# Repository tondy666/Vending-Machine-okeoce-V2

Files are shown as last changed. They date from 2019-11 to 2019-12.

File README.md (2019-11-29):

# simple-vending-mechine
merupakan project untuk sistem embeded yaitu bertujuan untuk membuat vending mechine dengan konsep sederhana dengan mengguunakan microkontroller STM32F103C8

SIMPLE VENDING MECHINE
Penerapan algoritma vending mechine secara sederhana dengan mengunakan Algoritma State Mechine dengan mengunakan Schedular(Timer) pada STM32F103C8.
dengan menggunakan Presacaller adalah 0 dan Auto Reload Register adalah 72 diharapkan melakukan task yang ditentukan setiap 1uS

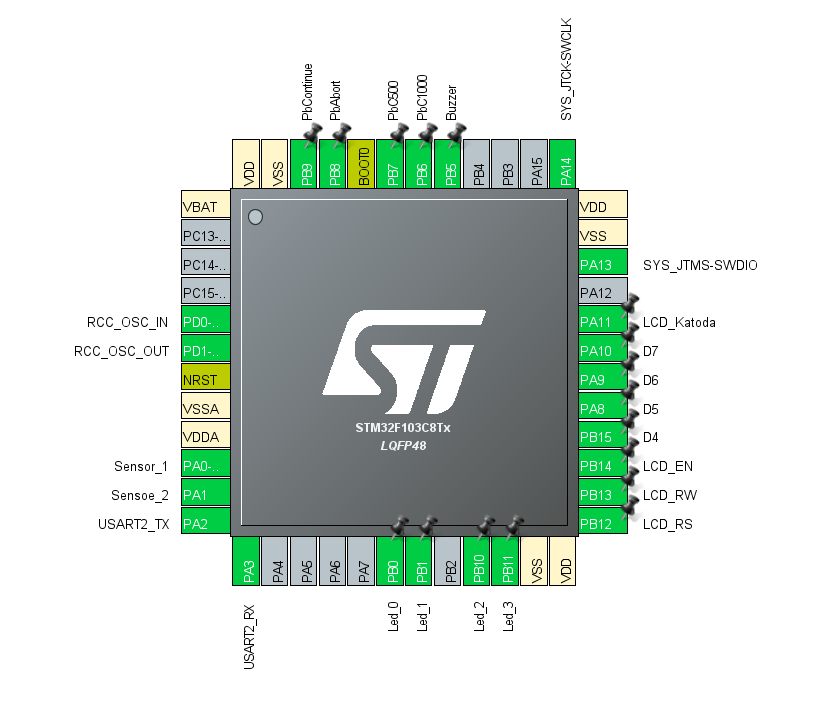
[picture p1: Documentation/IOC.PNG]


Diatas merupakan pinout konfigurasi yang digunakan pada project kali ini. menggunakan LCD 20x4 dan LED 5mm untuk interface

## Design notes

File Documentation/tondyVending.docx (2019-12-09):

LAPORAN PROJECT SISTEM EMBEDDED

APLIKASI TIMESTATE MACHINE PADA VENDING MACHINE

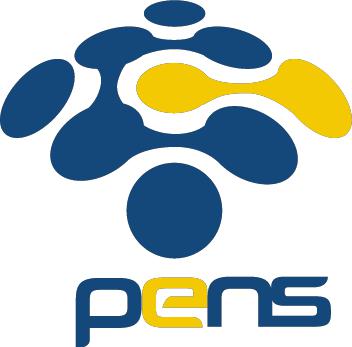
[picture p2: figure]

Disusun Oleh :

Tondi Taufiq Akbar Nasution 1110171048

3 D4 ELEKTRONIKA B

PROGRAM STUDI TEKNIK ELEKTRONIKA

DEPARTEMEN ELEKTRO

POLITEKNIK ELEKTRONIKA NEGERI SURABAYA

2019

LAPORAN PROJECT SISTEM EMBEDDED

APLIKASI TIMESTATE MACHINE PADA VENDING MACHINE

I. TUJUAN
1. Mahasiswa dapat membuat program timestate machine dengan menggunakan ARM
2. Mahasiswa dapat mengimplementasikan program timestate machine menggunakan pemrograman berstruktur dan mekanisme time out dalam suatu alat.
II. DASAR TEORI

II.1 ARM (STM32F103C8T6)

Arsitektur ARM merupakan arsitektur prosesor (https://id.wikipedia.org/wiki/Prosesor) 32-bit RISC yang dikembangkan oleh ARM Limited. Dikenal sebagai Advanced RISC Machine di mana sebelumnya dikenal sebagai Acorn RISC Machine. Pada awalnya merupakan prosesor desktop yang sekarang didominasi oleh keluarga x86. Namun desain yang sederhana membuat prosesor ARM cocok untuk aplikasi berdaya rendah. Hal ini membuat prosesor ARM mendominasi pasar mobile electronic dan embedded system di mana membutuhkan daya dan harga yang rendah.

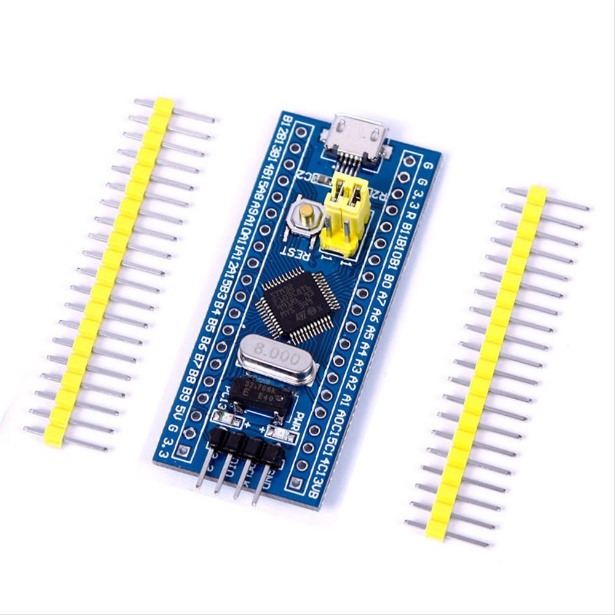
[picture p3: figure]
Hasil gambar untuk pengertian arm stm32f103c8t6"

STM32 adalah mikrokontroler berbasis inti prosesor 32 bit RISC ARM Cortex-M7, Cortex-M4F, Cortex-M3, Cortex-M0+, dan Cortex-M0 dari STMicrelectronics. Mikrokontroler ini mempunyai frekuensi clock tinggi, umumnya berada pada kisaran 72MHz atau lebih.

Gambar II.1 STM32F103C8T6

II.2 I2C LCD 20X4

LCD atau Liquid Crystal Display adalah suatu jenis media display (tampilaan) yang dibuat menggunakan teknologi CMOS logic yang bekerja dengan tidak menghasilkan cahaya namun memantulkan cahaya yang ada disekeliingnya terhadap front-lit atau mentransmisikan cahaya dari back-lit. LCD berfungsi sebagai penampil data baik dalam bentuk huruf, angka, karakter ataupun grafik.

Yang dimaksud dengan I2C LCD adalah modul LCD yang dikendalikan secara serial sinkron dengan protocol I2C/IIC (Inter Integrated Circuit) atau TWI (Two Wire Interface). Normalnya, modul LCD dikendalikan secara parallel baik untuk jalur data maupun kontrolnya. Namun, jalur parallel akan memakan banyak pin disisi controller (misal Arduino, Android, Komputer, dll). Setidaknya kita akan membutuhkan 6 atau 7 pin untuk mengendalikan sebuah modul LCD. Dengan demikian untuk sebuah controller yang “sibuk” dan harus, mengendalikan banyak I/O, menggunakan jalur parallel adalah solusi yang kurang tepat.

Arduino sudah mendukung protocol I2C/IIC. Di papan Arduino Uno, port I2C terletak pada pin A4 untuk jalur SDA (Serial Data) dan pin A5 untuk jalur SCL (Serial Clock), jangan lupa untuk menghubungkan jalur kabel ground antara Arduino dengan perangkat I2C client. Untuk sisi software, Arduino sudah cukup membantu kita bekerja dengan protocol ini melalui library ‘Wire.h’. Berikutnya, library ini akan dimanfaatkan untuk mengkonversi jalur parallel LCD menjadi jalur serial I2C. Kita dapat secara mudah melakukannya, namun agar lebih mudah kita dapat melakukannya dengan menggunakan library LiquidCrystal_I2C.h (bersama dengan library LCD.h).

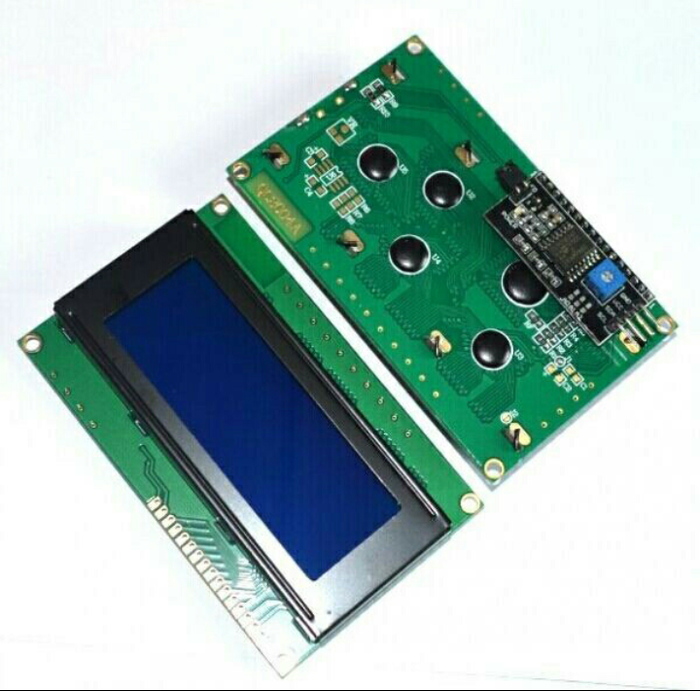
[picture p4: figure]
Hasil gambar untuk lcd 20x4 i2c"

Gambar II.2 Konfigurasi pin I2C LCD 20x4

III. ALAT DAN BAHAN
1. Laptop yang sudah terinstall software Arduino IDE 1 buah
2. ARM (STM32F103C8T6) 1 buah
3. I2C LCD 20x4 1 buah
4. ST-Link 1 buah
5. USB TTL 1 buah
6. Push Button 4 buah
7. Kabel jumper secukupnya
8. Kertas Duplex 1 buah
9. Lem tembak 1 buah
10. Cutter 1 buah
11. Gunting 1 buah
IV. PROSEDUR

IV.I Pemrograman dan Penyetinggan Pada STM32CubeIDE

1. Membuka aplikasi STM32CubeIDE pada PC
2. Memastikan USB TTL sudah terdeteksi oleh PC
3. Menuliskan program seperti dibawah ini :
  3.1 Program Pada task.c

#include "main.h"

#include "MyTask.h"

#include "MyLCD.h"

#include "MyUART.h"

#include "MySeOS.h"

unsigned char Button_Continue(void);

unsigned char Button_Abort(void);

unsigned char Button_C1000(void);

unsigned char Button_C500(void);

void Led_Init(void);

void Led_IndexStart(void);

void Led_c500(void);

void Led_Buffer(void);

void Led_Abort(void);

void Led_Continue(void);

#define Continue HAL_GPIO_ReadPin(PbContinue_GPIO_Port, PbContinue_Pin)==GPIO_PIN_RESET

#define Abort HAL_GPIO_ReadPin(PbAbort_GPIO_Port, PbAbort_Pin)==GPIO_PIN_RESET

#define Pb1000 HAL_GPIO_ReadPin(PbC1000_GPIO_Port, PbC1000_Pin)==GPIO_PIN_RESET

#define pb500 HAL_GPIO_ReadPin(PbC500_GPIO_Port, PbC500_Pin)==GPIO_PIN_RESET

#define BuzzerOn HAL_GPIO_WritePin(Buzzer_GPIO_Port, Buzzer_Pin, GPIO_PIN_SET)

#define BuzzerOff HAL_GPIO_WritePin(Buzzer_GPIO_Port, Buzzer_Pin, GPIO_PIN_RESET)

enum state {start, startdelay, finishdelay, koinkurang, kembali, buffer, index_start, c500, dropStuff, dropCoin, batal} Condition;

volatile uint32_t timeout=0;

volatile uint32_t i=0;

volatile uint8_t state_kembali=0;

unsigned int Coint_500=0;

unsigned int Coint_1000=0;

volatile uint64_t Jml_tunai = 0;

volatile uint16_t Coin=0;

volatile uint16_t Coin_temp=0;

volatile uint64_t Jml_kembali=0;

char dis_coint;

_Bool Kembali500 =0;

_Bool Kembali1000 =0;

_Bool Abort500=0;

_Bool Abort1000=0;

_Bool AbortTotal=0;

_Bool RunEnable =1;

void MyTask_Init(void)

{

timeout=0;

Condition=start;

Led_Init();

LCD_Init();

}

void MyTask_Run(void)

{

switch(Condition){

case start:

{

LCD_SetCursor(0, 0);LCD_Print("Vending Machine");

LCD_SetCursor(0, 1);LCD_Print("OKE OCE 2019");

Led_Init();

Condition=startdelay;

break;

}

case startdelay:

{

BuzzerOn;

if(++timeout>250000){

LCD_SetCursor(0, 2);LCD_Print("Masukkan Coin :");

timeout=0;

BuzzerOff;

MyTask_Display(RunEnable);

Condition=index_start;

}

break;

}

case c500:

{

Led_c500();

if(Button_C500()){

Coin=5;

Coin_temp+=5;

Jml_tunai+=5;

MyTask_Display(RunEnable);

Condition=buffer;

}

if(Button_C1000()){

Coin=10;

Coin_temp+=10;

Kembali500=!(Kembali500);

Condition=kembali;

}

if(Button_Abort()){

Led_Abort();

LCD_Clear();

LCD_SetCursor(0, 0);LCD_Print("Transaksi gagal");

Condition=batal;

}

if(Button_Continue()){

BuzzerOn;

LCD_Clear();

LCD_SetCursor(0, 1);LCD_Print("Transaksi Gagal");

LCD_SetCursor(0, 2);LCD_Print("MAAF COIN KURANG");

Condition=koinkurang;

}

break;

}

case koinkurang:

{

if(++timeout>1000000){

timeout=0;

LCD_Clear();

LCD_SetCursor(0, 0);LCD_Print("Vending Machine");

LCD_SetCursor(0, 1);LCD_Print("OKE OCE 2019");

LCD_SetCursor(0, 2);LCD_Print("Masukkan Coin:");

MyTask_Display(RunEnable);

BuzzerOff;

Condition=c500;

}

break;

}

case buffer:

{

Led_Buffer();

if(Button_C500()){

Coin=5;

Coin_temp+=5;

Kembali500=!(Kembali500);

Condition=kembali;

}

if(Button_C1000()){

Coin=10;

Coin_temp+=10;

Kembali1000=!(Kembali1000);

Condition=kembali;

}

if(Button_Continue()){

Condition=dropStuff;

}

if(Button_Abort()){

Led_Abort();

LCD_Clear();

LCD_SetCursor(0, 0);LCD_Print("Transaksi gagal");

Condition=batal;

}

break;

}

case dropCoin:

{

break;

}

case dropStuff:

{

Led_Continue();

LCD_Clear();

LCD_SetCursor(0, 1);LCD_Print("Minuman Keluar");

LCD_SetCursor(0, 2);

LCD_Print("Uang Kembali");LCD_SetCursor(13, 2);LCD_PrintNum(Jml_kembali);LCD_Print("00");

Condition=finishdelay;

break;

}

case index_start:

{

Led_IndexStart();

if(Button_C500()){

Coin=5;

Coin_temp+=5;

Jml_tunai+=5;

MyTask_Display(RunEnable);

Condition=c500;

}

if(Button_C1000()){

Coin=10;

Coin_temp+=10;

Jml_tunai+=10;

MyTask_Display(RunEnable);

Condition=buffer;

}

break;

}

case finishdelay:

{

if(++timeout>1000000){

timeout=0;

Coin=0;

Coin_temp=0;

Jml_tunai=0;

Jml_kembali=0;

LCD_Clear();

Condition=start;

}

break;

}

case kembali:

{

if(Kembali500){

Jml_tunai=10;

Jml_kembali+=5;

Kembali500=!(Kembali500);

MyTask_Display(RunEnable);

Condition=buffer;

}

if(Kembali1000){

Jml_tunai=10;

Jml_kembali+=10;

Kembali1000=!(Kembali1000);

MyTask_Display(RunEnable);

Condition=buffer;

}

break;

}

case batal:

{

LCD_SetCursor(0, 2);

LCD_Print("Uang Kembali");LCD_SetCursor(13, 2);LCD_PrintNum(Coin_temp);LCD_Print("00");

if(++i>30){

i=0;

Condition=finishdelay;

}

break;

}

}

}

void MyTask_Error_Handler(_Bool Enable, char *pData)

{

}

void MyTask_Display(_Bool Enable)

{

if(Enable){

LCD_SetCursor(15, 2);LCD_PrintNum(Coin);LCD_Print("00 ");

LCD_SetCursor(0, 3);LCD_Print("Total: ");LCD_PrintNum(Jml_tunai);LCD_Print("00 ");LCD_SetCursor(15, 3);LCD_PrintNum(Jml_kembali);LCD_Print("00 ");

}

}

/*Sensor*/

unsigned char Button_Continue(void)

{

static unsigned char bouncing=0xFF;

unsigned char Flagdetect=0;

if(Continue){

if(++timeout>500000){

BuzzerOn;

}

else{

bouncing=(bouncing<<1);

}

}

else{

bouncing=(bouncing<<1)|1;

timeout=0;

}

if(bouncing==0x03){

UART_Print("Tranfer_OK\n\r");

Flagdetect=1;

}

return Flagdetect;

}

unsigned char Button_Abort(void)

{

static unsigned char bouncing=0xFF;

unsigned char Flagdetect=0;

if(Abort){

bouncing=(bouncing<<1);

}

else{

bouncing=(bouncing<<1)|1;

}

if(bouncing==0x03){

UART_Print("Transfer_Cancel\n\r");

BuzzerOff;

Flagdetect=1;

}

return Flagdetect;

}

unsigned char Button_C1000(void)

{

static unsigned char bouncing=0xFF;

unsigned char Flagdetect=0;

if(Pb1000){

if(++timeout>500000){

BuzzerOn;

}

else{

bouncing=(bouncing<<1);

}

}

else{

bouncing=(bouncing<<1)|1;

timeout=0;

}

if(bouncing==0x03){

UART_Print("1000\n\r");

Flagdetect=1;

}

return Flagdetect;

}

unsigned char Button_C500(void)

{

static unsigned char bouncing=0xFF;

unsigned char Flagdetect=0;

if(pb500){

if(++timeout>500000){

BuzzerOn;

}

else{

bouncing=(bouncing<<1);

}

}

else{

bouncing=(bouncing<<1)|1;

timeout=0;

}

if(bouncing==0x03){

UART_Print("500\n\r");

Flagdetect=1;

}

return Flagdetect;

}

/*Led Configuration*/

void Led_Init(void)

{

HAL_GPIO_WritePin(Led_0_GPIO_Port, Led_0_Pin, GPIO_PIN_SET);

HAL_GPIO_WritePin(Led_1_GPIO_Port, Led_1_Pin, GPIO_PIN_SET);

HAL_GPIO_WritePin(Led_2_GPIO_Port, Led_2_Pin, GPIO_PIN_SET);

HAL_GPIO_WritePin(Led_3_GPIO_Port, Led_3_Pin, GPIO_PIN_SET);

}

void Led_IndexStart(void)

{

HAL_GPIO_WritePin(Led_0_GPIO_Port, Led_0_Pin, GPIO_PIN_RESET);

HAL_GPIO_WritePin(Led_1_GPIO_Port, Led_1_Pin, GPIO_PIN_SET);

HAL_GPIO_WritePin(Led_2_GPIO_Port, Led_2_Pin, GPIO_PIN_SET);

HAL_GPIO_WritePin(Led_3_GPIO_Port, Led_3_Pin, GPIO_PIN_SET);

}

void Led_c500(void)

{

HAL_GPIO_WritePin(Led_0_GPIO_Port, Led_0_Pin, GPIO_PIN_SET);

HAL_GPIO_WritePin(Led_1_GPIO_Port, Led_1_Pin, GPIO_PIN_RESET);

HAL_GPIO_WritePin(Led_2_GPIO_Port, Led_2_Pin, GPIO_PIN_SET);

HAL_GPIO_WritePin(Led_3_GPIO_Port, Led_3_Pin, GPIO_PIN_SET);

}

void Led_Buffer(void)

{

HAL_GPIO_WritePin(Led_0_GPIO_Port, Led_0_Pin, GPIO_PIN_SET);

HAL_GPIO_WritePin(Led_1_GPIO_Port, Led_1_Pin, GPIO_PIN_RESET);

HAL_GPIO_WritePin(Led_2_GPIO_Port, Led_2_Pin, GPIO_PIN_RESET);

HAL_GPIO_WritePin(Led_3_GPIO_Port, Led_3_Pin, GPIO_PIN_SET);

}

void Led_Abort(void)

{

HAL_GPIO_WritePin(Led_0_GPIO_Port, Led_0_Pin, GPIO_PIN_SET);

HAL_GPIO_WritePin(Led_1_GPIO_Port, Led_1_Pin, GPIO_PIN_SET);

HAL_GPIO_WritePin(Led_2_GPIO_Port, Led_2_Pin, GPIO_PIN_SET);

HAL_GPIO_WritePin(Led_3_GPIO_Port, Led_3_Pin, GPIO_PIN_RESET);

}

void Led_Continue(void)

{

HAL_GPIO_WritePin(Led_0_GPIO_Port, Led_0_Pin, GPIO_PIN_RESET);

HAL_GPIO_WritePin(Led_1_GPIO_Port, Led_1_Pin, GPIO_PIN_SET);

HAL_GPIO_WritePin(Led_2_GPIO_Port, Led_2_Pin, GPIO_PIN_RESET);

HAL_GPIO_WritePin(Led_3_GPIO_Port, Led_3_Pin, GPIO_PIN_SET);

}

3 Melakukan proses build dan memastikan tidak terjadi error pada program
4 Mem-build dan meng-upload program
5 Mencoba program dan segera melakukan proses.

IV.III Mekanik

1. Menyiapkan alat dan bahan

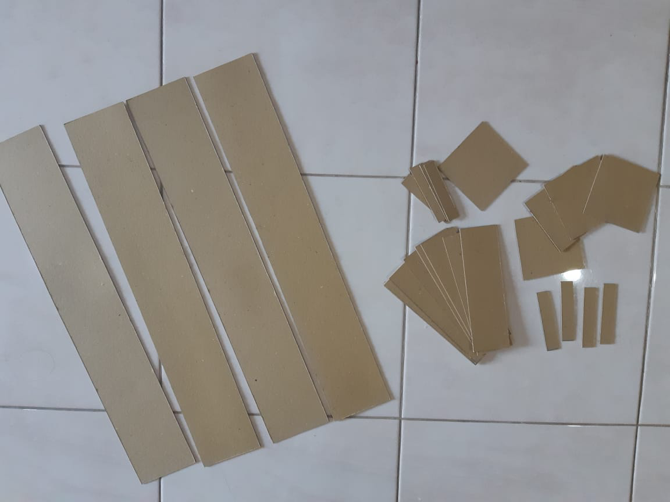
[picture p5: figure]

2. Membuat rancangan untuk box yang akan diisi dengan rangkaian hardware dengan ukuran sesuai yang diinginkan.

Berikut ini gambar langkah-langkah pembuatan box :

Gambar 1. Kertas yang sudah siap dirangkai untuk membentuk box

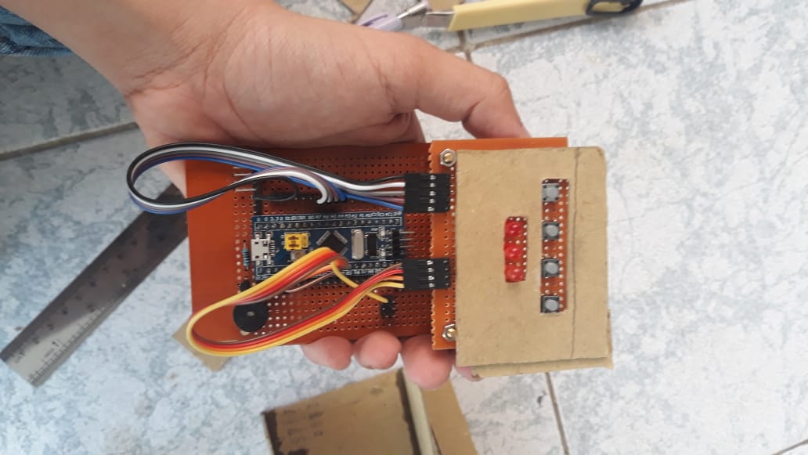
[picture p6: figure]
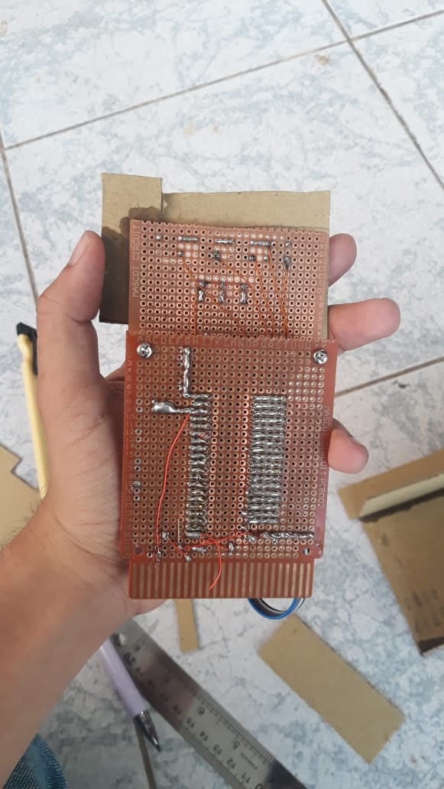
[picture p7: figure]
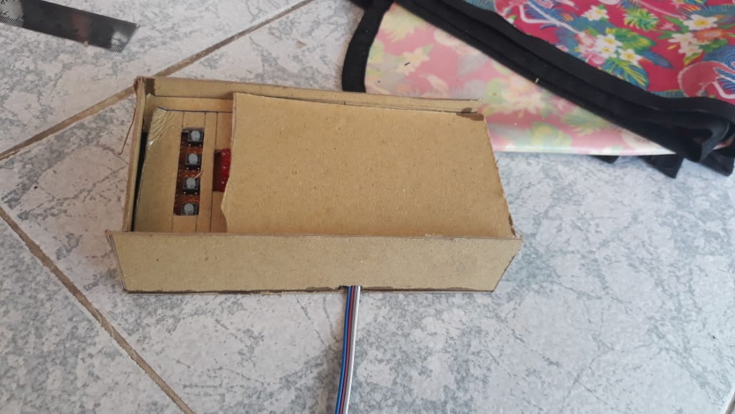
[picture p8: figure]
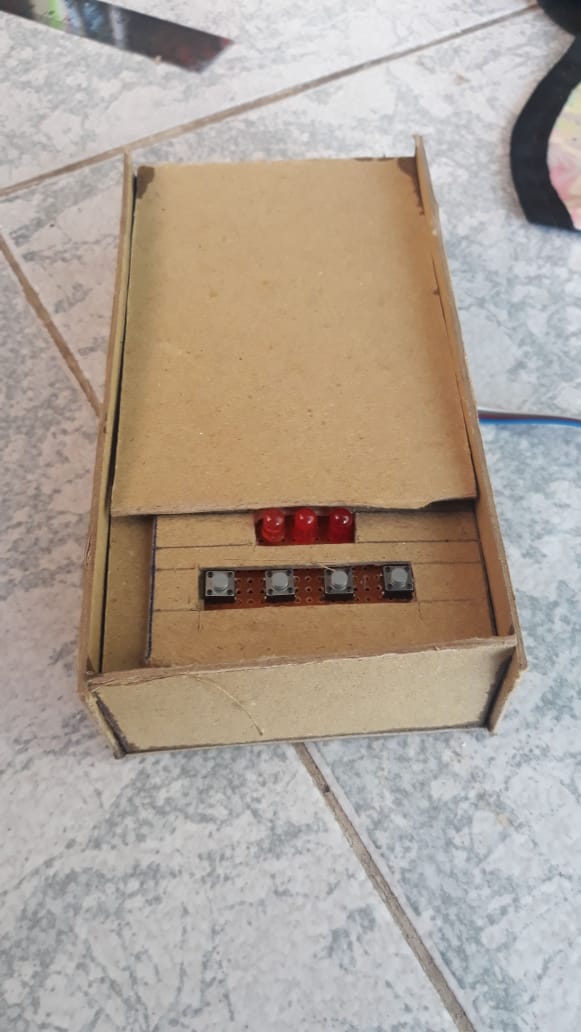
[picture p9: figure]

Gambar 2. Hardware yang sudah dikemas dalam box

V. ANALISA DATA

Pada project kali ini tentang aplikasi timestate machine with arm pada vending machine dapat dianalisa bahwa ketika kita memasukkan nilai 500 maka state akan menuju s500 dan ketika memasukkan nilai 500 lagi maka state akan menuju s1000 , dan ketika memasukkan nilai 1000 maka state akan menuju s1000 , ketika coin melebihi 1000 maka terdapat kembalian dan coin dapat diproses untuk pembelian sebuah minuman pada vending machine dengan arm dan ditampilkan pada layar LCD.

KESIMPULAN

Timestate machine adalah sebuah metode (dalam proses pemrograman) untuk menyederhanakan sebuah permasalahan yang runtut

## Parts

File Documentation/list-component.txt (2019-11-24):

LM7805
Male header
female header
male header tk
push button switch
switch on/off small
C104 cramic
regulator ams1117
dioda 1n0004/7
led 5mm
resistor 1kOhm
resistor 470Ohm
buzzer 5v
C828

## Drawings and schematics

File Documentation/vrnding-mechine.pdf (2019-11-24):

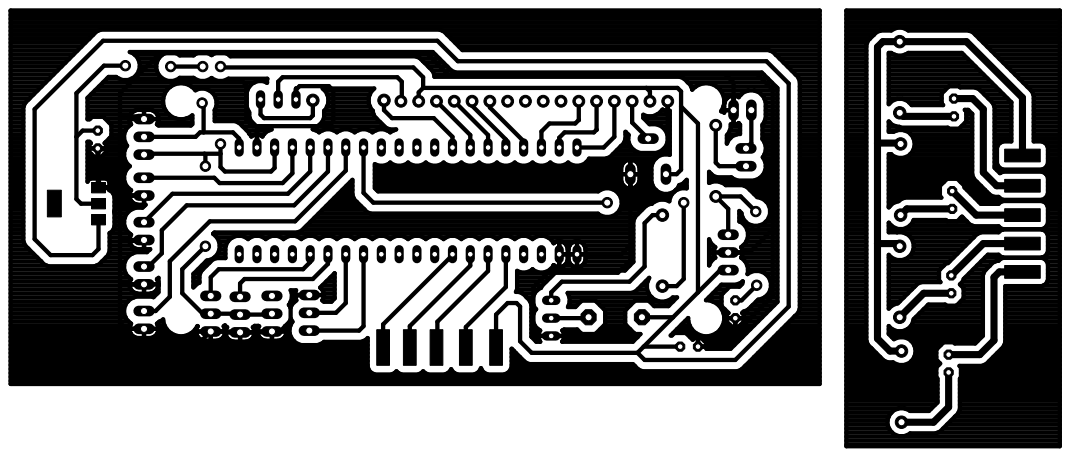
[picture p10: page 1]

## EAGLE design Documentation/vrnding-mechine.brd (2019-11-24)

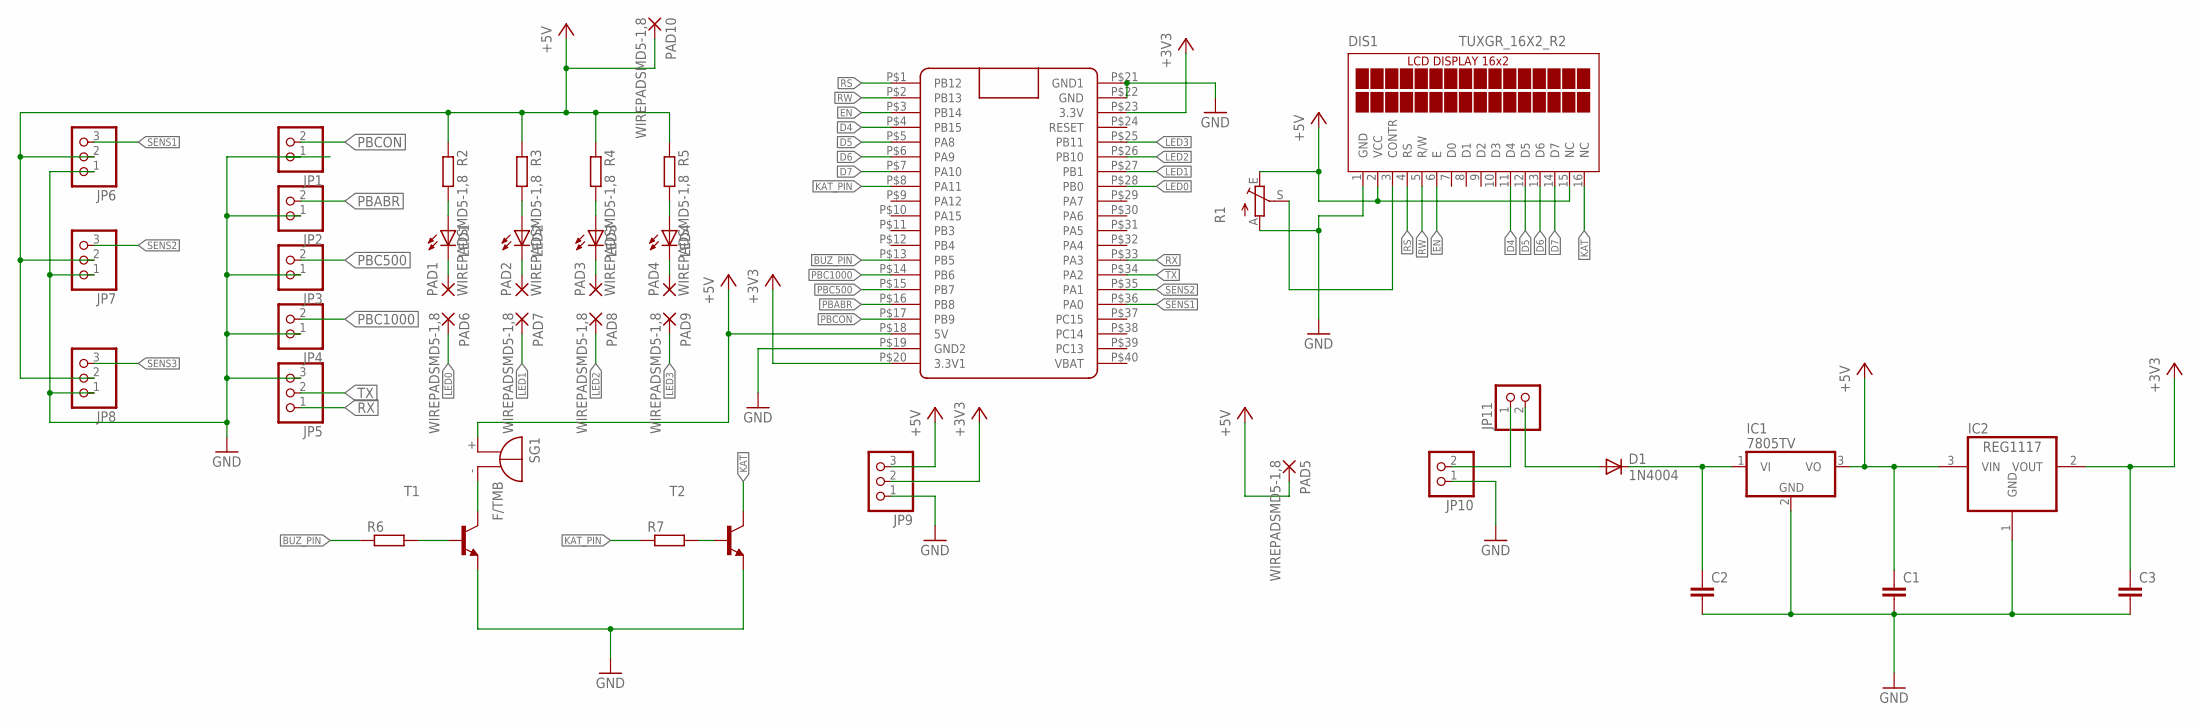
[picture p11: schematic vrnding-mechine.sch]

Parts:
C1, C2, C3: C-EU025-030X050; C025-030X050
D1: 1N4004; DO41-10
DIS1: TUXGR_16X2_R2
IC1: 7805TV; TO220V
IC2: REG1117; SOT223
JP1, JP2, JP3, JP4, JP10, JP11: PINHD-1X2; 1X02
JP5, JP6, JP7, JP8, JP9: PINHD-1X3; 1X03
LED1, LED2, LED3, LED4: LED5MM
PAD1, PAD2, PAD3, PAD4, PAD5, PAD6, PAD7, PAD8, PAD9, PAD10: WIREPADSMD5-1,8; 5-1,8
R1: TRIM_EU-CA6V; CA6V
R2, R3, R4, R5, R6, R7: R-EU_0309/10; 0309/10
SG1: F/TMB
T1, T2: -NPN-TO92-ECB; TO92-ECB
U$1: BLUE_PILL

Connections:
+3V3: C3.1, IC2.2 (VOUT), JP9.2, U$1.P$20 (3.3V1), U$1.P$23 (3.3V)
+5V: C1.1, DIS1.2 (VCC), DIS1.15 (NC), IC1.3 (VO), IC2.3 (VIN), JP6.2, JP7.2, JP8.2, JP9.3, PAD5.1, PAD10.1, R1.E, R2.1, R3.1, R4.1, R5.1, SG1.+, U$1.P$18 (5V)
BUZ_PIN: R6.1, U$1.P$13 (PB5)
D4: DIS1.11 (D4), U$1.P$4 (PB15)
D5: DIS1.12 (D5), U$1.P$5 (PA8)
D6: DIS1.13 (D6), U$1.P$6 (PA9)
D7: DIS1.14 (D7), U$1.P$7 (PA10)
EN: DIS1.6 (E), U$1.P$3 (PB14)
GND: C1.2, C2.2, C3.2, DIS1.1 (GND), IC1.2 (GND), IC2.1 (GND), JP1.1, JP2.1, JP3.1, JP4.1, JP5.3, JP6.1, JP7.1, JP8.1, JP9.1, JP10.1, R1.A, T1.E, T2.E, U$1.P$19 (GND2), U$1.P$21 (GND1), U$1.P$22 (GND)
KAT: DIS1.16 (NC), T2.C
KAT_PIN: R7.1, U$1.P$8 (PA11)
LED0: PAD6.1, U$1.P$28 (PB0)
LED1: PAD7.1, U$1.P$27 (PB1)
LED2: PAD8.1, U$1.P$26 (PB10)
LED3: PAD9.1, U$1.P$25 (PB11)
unnamed: DIS1.3 (CONTR), R1.S
unnamed: SG1.-, T1.C
unnamed: R6.2, T1.B
unnamed: LED1.A, R2.2
unnamed: LED2.A, R3.2
unnamed: LED3.A, R4.2
unnamed: LED4.A, R5.2
unnamed: R7.2, T2.B
unnamed: LED2.K (C), PAD2.1
unnamed: LED1.K (C), PAD1.1
unnamed: LED3.K (C), PAD3.1
unnamed: LED4.K (C), PAD4.1
unnamed: JP10.2, JP11.1
unnamed: D1.A, JP11.2
unnamed: C2.1, D1.C, IC1.1 (VI)
PBABR: JP2.2, U$1.P$16 (PB8)
PBC500: JP3.2, U$1.P$15 (PB7)
PBC1000: JP4.2, U$1.P$14 (PB6)
PBCON: JP1.2, U$1.P$17 (PB9)
RS: DIS1.4 (RS), U$1.P$1 (PB12)
RW: DIS1.5 (R/W), U$1.P$2 (PB13)
RX: JP5.1, U$1.P$33 (PA3)
SENS1: JP6.3, U$1.P$36 (PA0)
SENS2: JP7.3, U$1.P$35 (PA1)
SENS3: JP8.3
TX: JP5.2, U$1.P$34 (PA2)

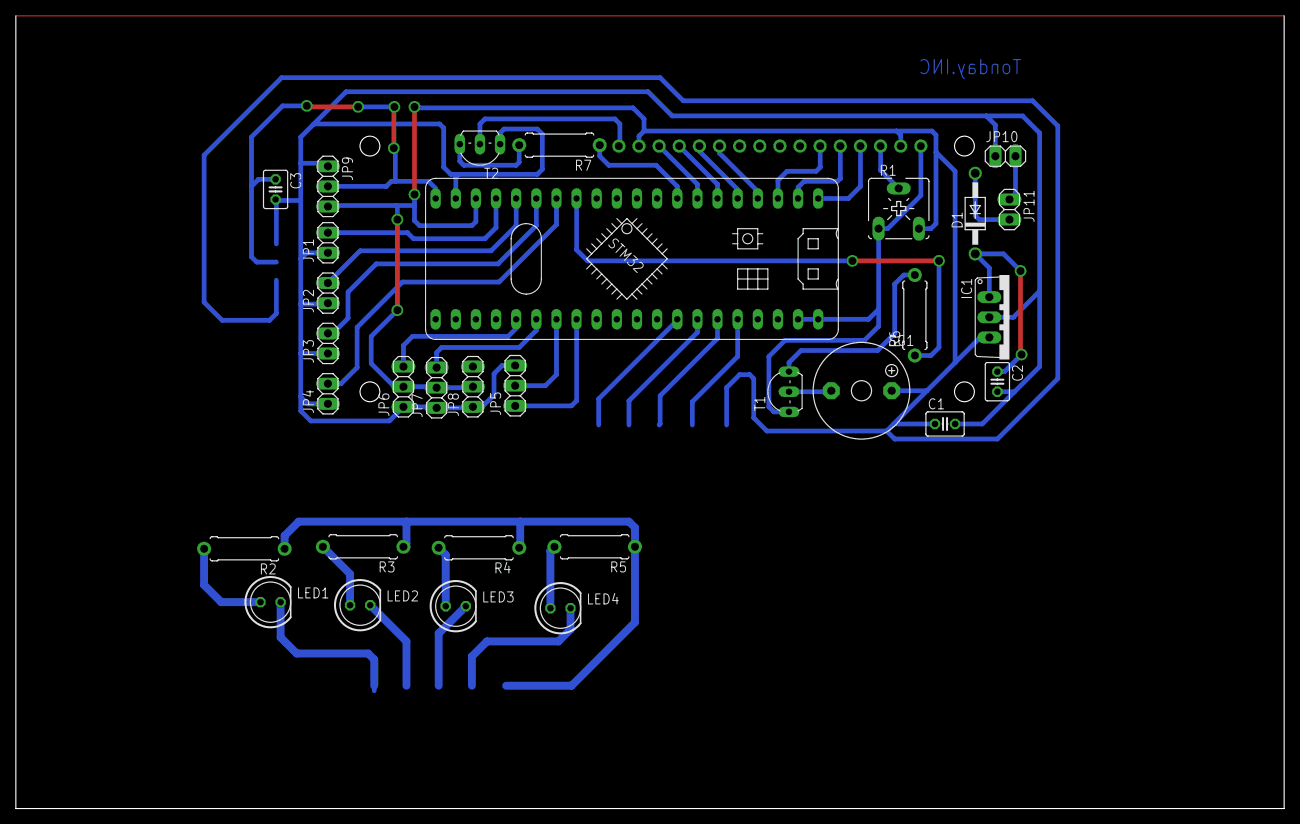
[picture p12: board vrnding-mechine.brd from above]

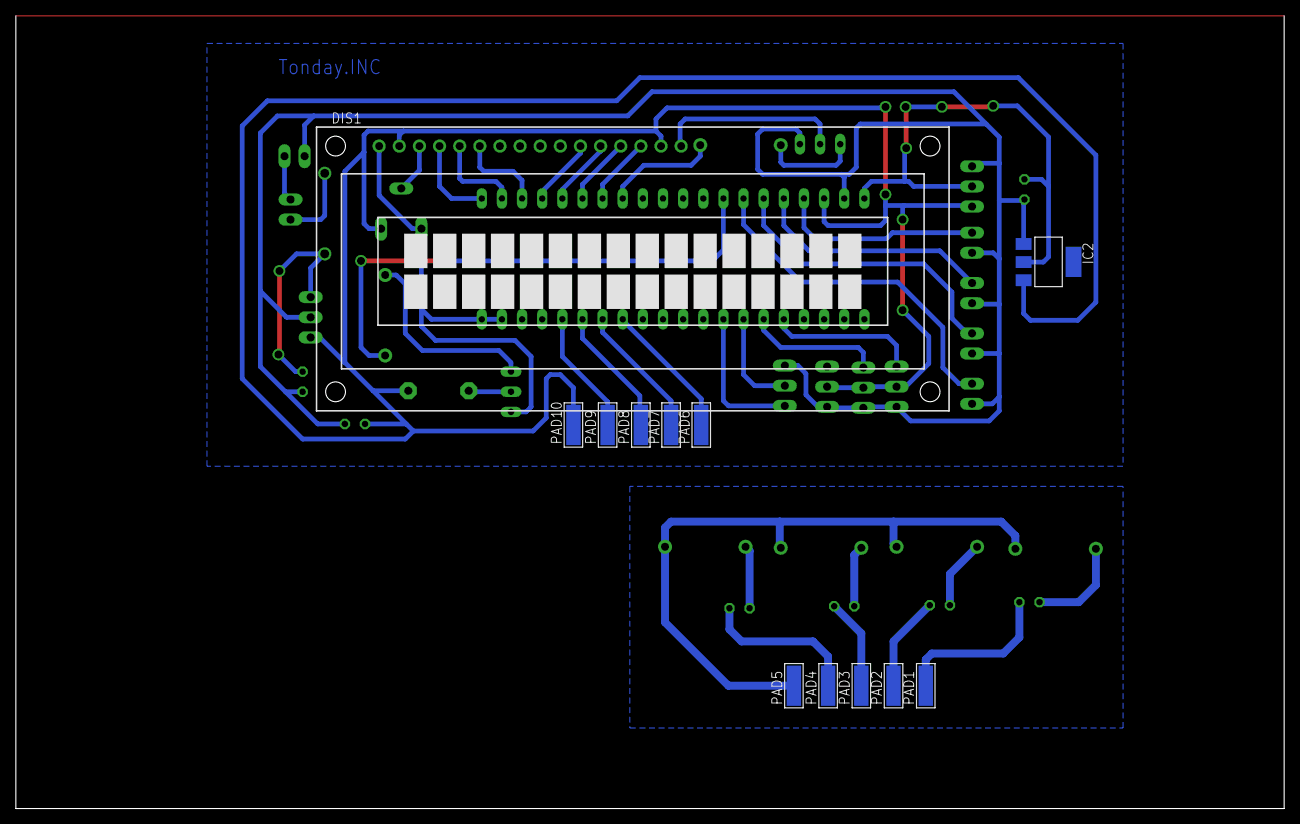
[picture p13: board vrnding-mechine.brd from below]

Board: 2 copper layers, 160.0 x 100.0 mm, 43 parts (12 on the bottom side), 40 nets.

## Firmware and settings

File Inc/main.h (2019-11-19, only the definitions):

#define Sensor_1_Pin GPIO_PIN_0
#define Sensor_1_GPIO_Port GPIOA
#define Sensoe_2_Pin GPIO_PIN_1
#define Sensoe_2_GPIO_Port GPIOA
#define Led_0_Pin GPIO_PIN_0
#define Led_0_GPIO_Port GPIOB
#define Led_1_Pin GPIO_PIN_1
#define Led_1_GPIO_Port GPIOB
#define Led_2_Pin GPIO_PIN_10
#define Led_2_GPIO_Port GPIOB
#define Led_3_Pin GPIO_PIN_11
#define Led_3_GPIO_Port GPIOB
#define LCD_RS_Pin GPIO_PIN_12
#define LCD_RS_GPIO_Port GPIOB
#define LCD_RW_Pin GPIO_PIN_13
#define LCD_RW_GPIO_Port GPIOB
#define LCD_EN_Pin GPIO_PIN_14
#define LCD_EN_GPIO_Port GPIOB
#define D4_Pin GPIO_PIN_15
#define D4_GPIO_Port GPIOB
#define D5_Pin GPIO_PIN_8
#define D5_GPIO_Port GPIOA
#define D6_Pin GPIO_PIN_9
#define D6_GPIO_Port GPIOA
#define D7_Pin GPIO_PIN_10
#define D7_GPIO_Port GPIOA
#define LCD_Katoda_Pin GPIO_PIN_11
#define LCD_Katoda_GPIO_Port GPIOA
#define Buzzer_Pin GPIO_PIN_5
#define Buzzer_GPIO_Port GPIOB
#define PbC1000_Pin GPIO_PIN_6
#define PbC1000_GPIO_Port GPIOB
#define PbC500_Pin GPIO_PIN_7
#define PbC500_GPIO_Port GPIOB
#define PbAbort_Pin GPIO_PIN_8
#define PbAbort_GPIO_Port GPIOB
#define PbContinue_Pin GPIO_PIN_9
#define PbContinue_GPIO_Port GPIOB

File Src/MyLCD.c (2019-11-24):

/*
 * MyLCD.c
 *
 *  Created on: Nov 21, 2019
 *      Author:
 */

#include "main.h"
#include "MyLCD.h"
#include <stdio.h>


void LCD_Write4Bit(uint8_t data)
{
	HAL_GPIO_WritePin(D4_GPIO_Port, D4_Pin, ((data>>0)&1)? GPIO_PIN_SET:GPIO_PIN_RESET);
	HAL_GPIO_WritePin(D5_GPIO_Port, D5_Pin, ((data>>1)&1)? GPIO_PIN_SET:GPIO_PIN_RESET);
	HAL_GPIO_WritePin(D6_GPIO_Port, D6_Pin, ((data>>2)&1)? GPIO_PIN_SET:GPIO_PIN_RESET);
	HAL_GPIO_WritePin(D7_GPIO_Port, D7_Pin, ((data>>3)&1)? GPIO_PIN_SET:GPIO_PIN_RESET);
}
void LCD_Send(_Bool mode, uint8_t data)
{
	LCD_RW(0);
	if(mode){
		LCD_RS(1);
	}else{
		LCD_RS(0);
	}

	LCD_Write4Bit(data>>4);
	LCD_EN();
	LCD_Write4Bit(data);
	LCD_EN();
}
void LCD_Init(void)
{
	LCD_RW(0);

	LCD_Command(0x33);
	LCD_Command(0x32);
	LCD_Command(0x28);
	LCD_Command(0x0C);
	LCD_Command(0x06);
}
void LCD_Print(char *pData)
{
	while(*pData){
		LCD_Data(*pData++);
	}
}
void LCD_PrintNum(uint16_t numVal)
{
	char bufprint[20];
	sprintf(bufprint, "%d", numVal);
	LCD_Print(bufprint);
}
void LCD_SetCursor(uint8_t x, uint8_t y)
{
	if(y==0){
		LCD_Command(0x80+x);
	}
	if(y==1){
		LCD_Command(0xC0+x);
	}
	if(y==2){
		LCD_Command(0x94+x);
	}
	if(y==3){
		LCD_Command(0xD4+x);
	}
}
void LCD_Clear(void)
{
	LCD_Command(0x01);
}

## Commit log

2019-11-19 menambahkan file eagle pada Documentation/
    [vrnding-mechine.brd, vrnding-mechine.sch]
2019-11-22 menambahkan pdf untuk pcb cetak.
2019-11-24 menambahkan fitur led.
2019-11-25 merubah indikator led.
2019-12-02 Mengubah LED cancel

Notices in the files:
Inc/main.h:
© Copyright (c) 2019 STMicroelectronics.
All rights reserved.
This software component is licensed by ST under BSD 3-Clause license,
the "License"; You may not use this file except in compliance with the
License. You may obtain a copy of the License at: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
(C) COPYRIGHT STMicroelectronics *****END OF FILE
